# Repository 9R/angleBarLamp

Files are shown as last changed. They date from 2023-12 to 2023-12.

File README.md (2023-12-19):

# Folding AngleBarLamp

This is a folding lamp made out of 3d-printed parts and angle-bars. The design
was inspired by the lamps from 
[kliments workshoptoolset](https://github.com/kliment/workshoptoolset)

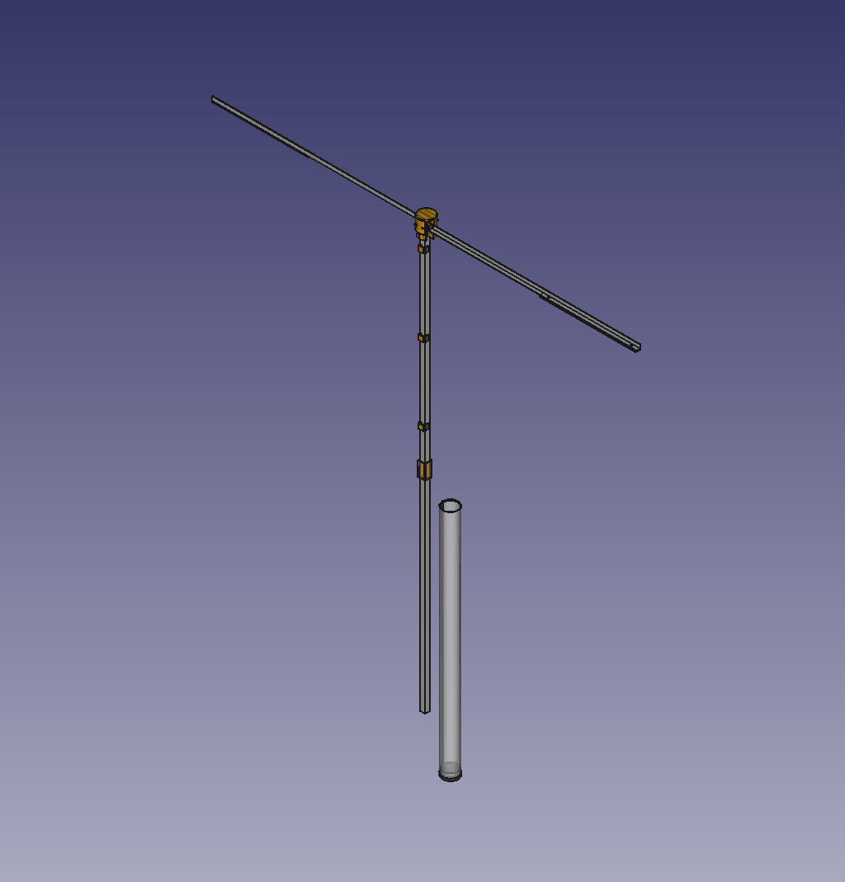
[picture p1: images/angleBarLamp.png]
angle bar lamp


The lamp parts were designed using [Freecad 0.21.1](https://www.freecad.org/)
and the
[assembly4 workbench v0.50.6](https://github.com/Zolko-123/FreeCAD_Assembly4).

## Printed parts

The parts don't require any special settings, recommended print parameters are:

* Tested with PLA, PETG should work as well.
* 4 or 5 perimenter layers
* no support required

### TopBlock

Make sure to print this part upside down to avoid the need for support material
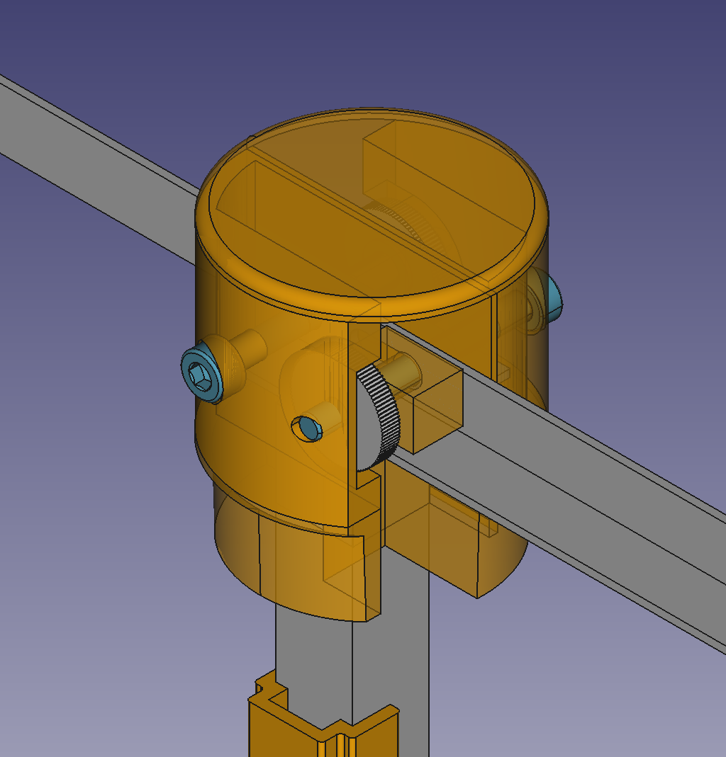
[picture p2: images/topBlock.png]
top block TopBlock


### 8mmSpacer
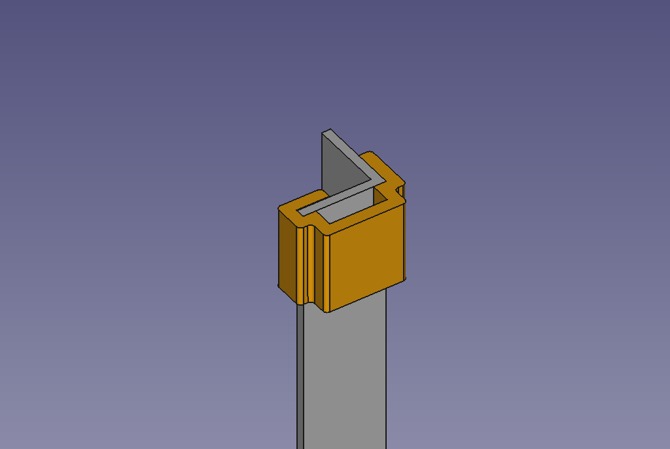
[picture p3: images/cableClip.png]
8mm spacer CableClip


### BottomBlock
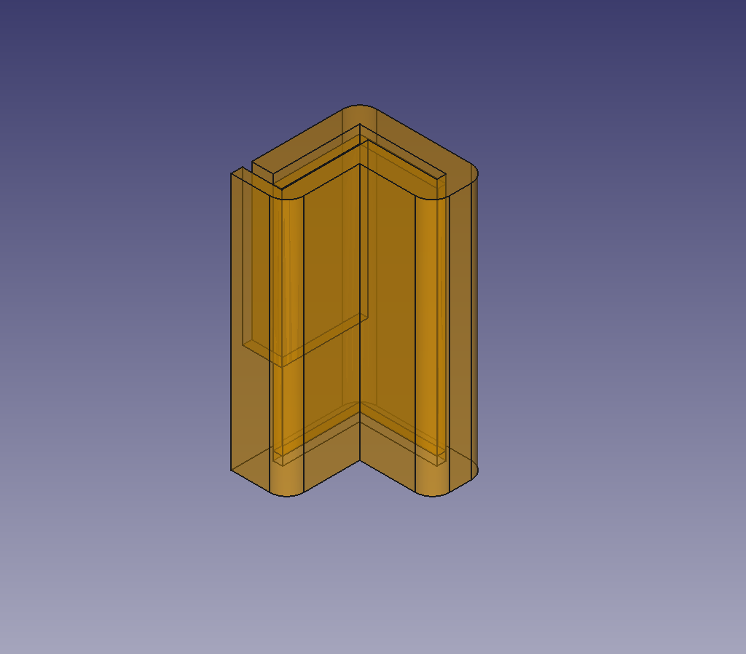
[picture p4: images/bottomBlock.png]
bottom block BottomBlock


### CableClips
cable clip CableClip

### BaseCap

If availabe this part can also be printed in TPU. That way you get a elastic,
more durable bumper at the bottom.
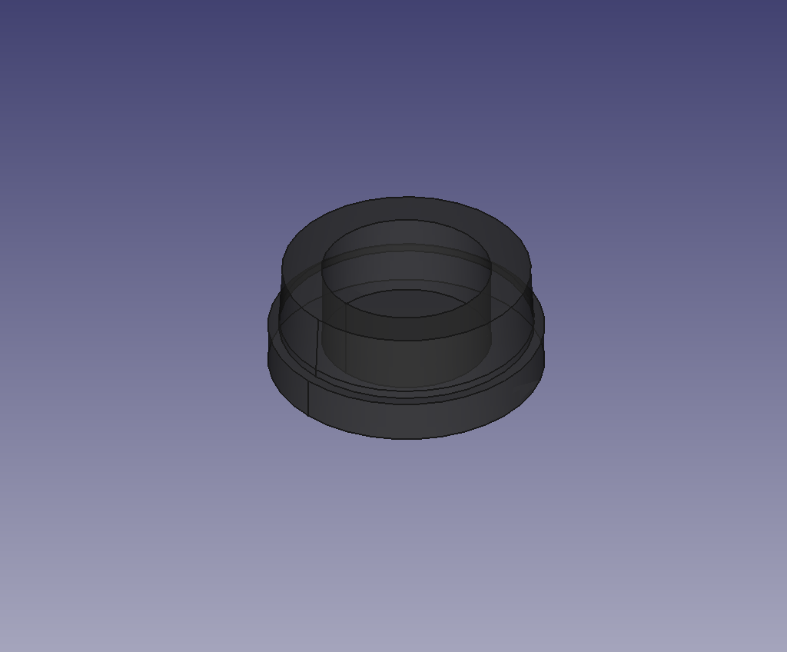
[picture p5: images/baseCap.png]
base cap BaseCap


## Other parts

### Screws & Nuts:
##### topBlock
  * 2x ISO4762 M3x28 hexagonal socket head
  * 2x DIN467 knurled flat nut (or similar)
      
##### COB LED attachment
  * 4x ISO7380-1 M3x4 button head

### Angle bars for arms and foot (length can be modified to suit needs):
  * 2x  8mm x 400mm aluminium angle bar
  * 2x 10mm x 400mm aluminium angle bar

#### 8mm bar latching mechanism
The tips of the 8mm bar need to be machined the create the latching mechanism.
When building a single lamp or a small series this can be done quite easily
by hand using a power drill, a round and a flat files.

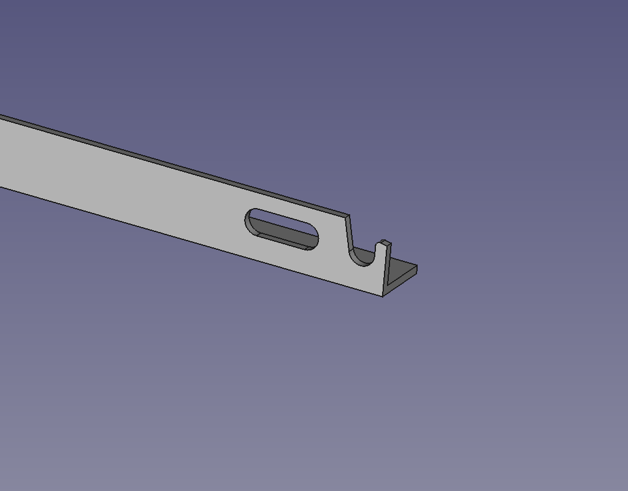
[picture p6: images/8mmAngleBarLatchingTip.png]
8mm angle bar tip 8mm angle bar latching tip


The exact dimensions cna be found in the ```sk_cuts``` sketch in
```angleBarLamp.FCStd```. When machining by hand, it is only important to
position the holes on the center line of the angle bar. Most other dimensions
will allow a tolerance of 0.2mm to still get a working mechanism.

![latch dimensions](images/8mmAngleBarLatchDimensions.png "latch dimensions")

##### Latch jig
A printable jig (```8mmLatchJig.stl```) can be used to transfer these
dimensions in a reproducable way for manual machining.

![latch jig](images/8mmAngleBarLatchJig.png "latch jig")

When building more lamps automating the machining process by generating g-code
for a CNC-mill with FreeCADs 
[Path workbench](https://wiki.freecad.org/Path_Workbench) should be considered.

### Housing
  * 480mm of DN32 HT pipe 

### Electronics:
  * 2x COB LEDs that suite your needs (a width of 8-10mm is recommended)
  * Power supply
  * Switch or dimmer (check workshoptoolset)
  * 2x 1.5m wire

## Folding Mechanism
![folding animation](images/foldingAnimation.gif "Folding mechanism")
![folding animation_closeup](images/foldingAnimationCloseup.gif "Folding mechanismCloseup")

### Running the animation in FreeCAD

* Open the assembly4 workbench
* Run "Animate Assembly" with these parameters

![animation parameters](images/animationParameters.png "")

### Background

This assembly is a top-down design (using a minimal master sketch).

Parts are attached using the master sketch for the axes of the rotating parts
as well as LCSs of adjacent parts.

Animation is controlled by the **time** variable. Nested conditional statements
execute the different parts of the motion as the **time** variable is
incremented. This way rotation and position parameters of the arms are
calculated in the attachment section of moving parts. To keep the expression
managable some intermediate variables are calculated in **Assembly/Variables**.

Some base dimensional parameters are kept in the **Spreadsheet** and can be
modified via the spreadsheet workbench.

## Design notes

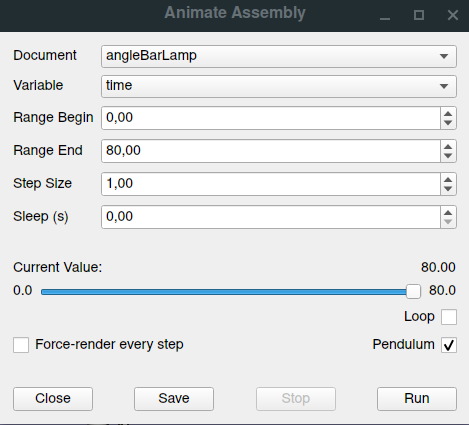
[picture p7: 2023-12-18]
images/animationParameters.png

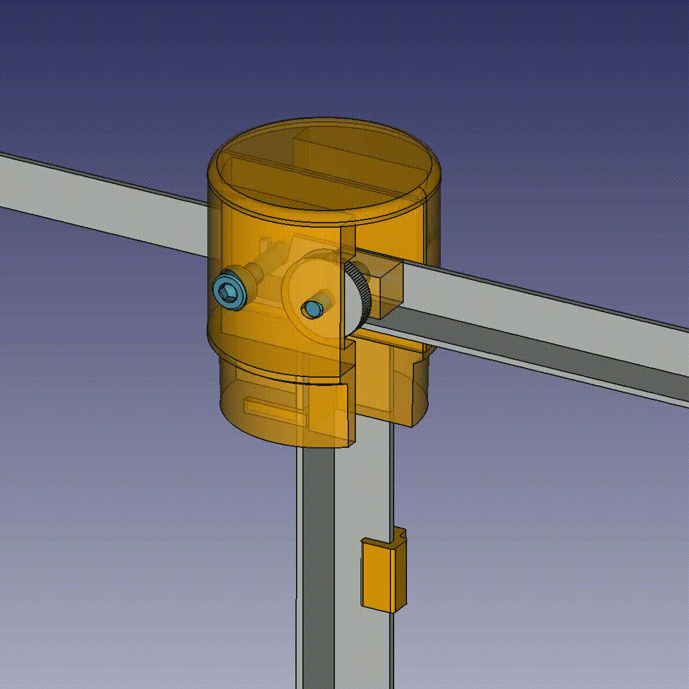
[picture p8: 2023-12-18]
images/foldingAnimationCloseup.gif

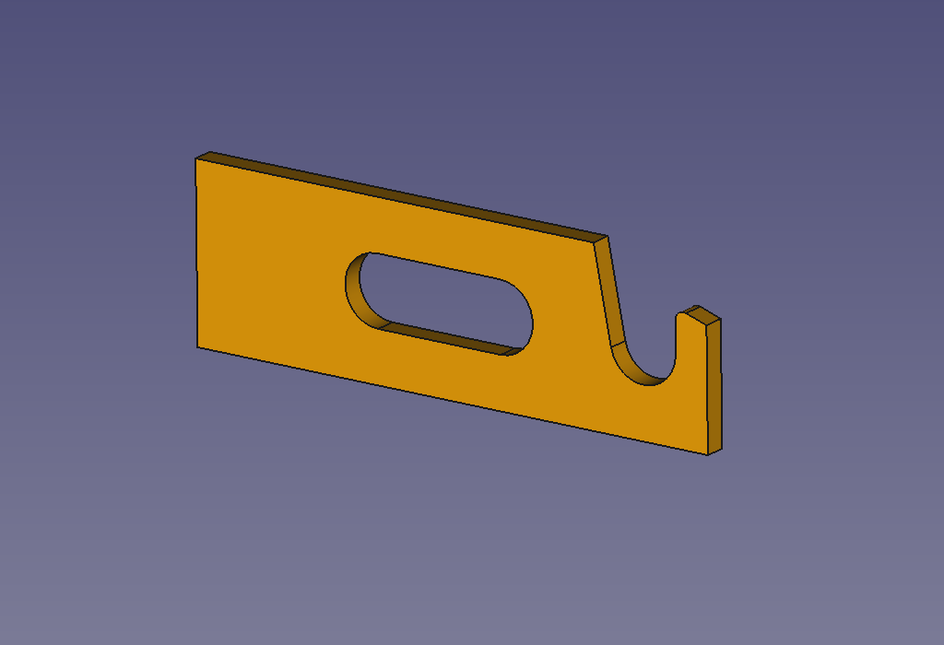
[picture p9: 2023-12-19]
images/8mmAngleBarLatchJig.png

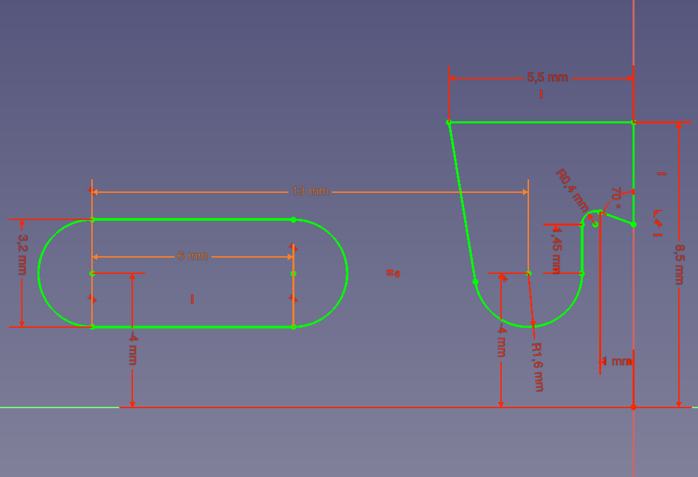
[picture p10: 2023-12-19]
images/8mmAngleBarLatchDimensions.png

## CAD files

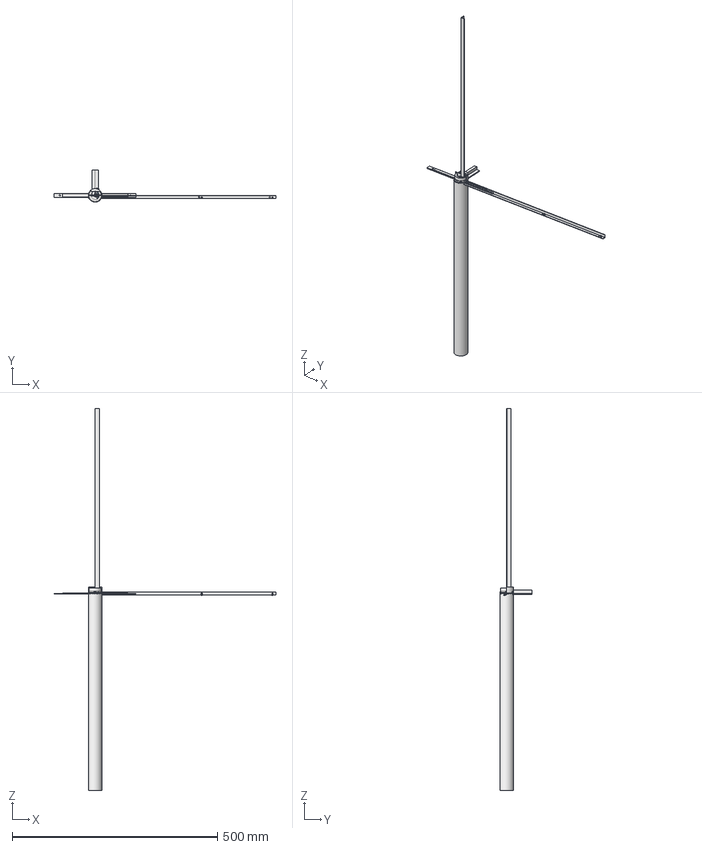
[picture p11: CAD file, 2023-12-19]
angleBarLamp.FCStd
540.0 x 78.5 x 930.0 mm
b_cableClip
template_L-profile_10mm_foot
b_base_cap
M3x28-Screw
M3x4-Screw
M3x4-Screw001
b_LProfile_8mm
b_bottom_connector
b_led
b_led_heatsink
b_nut
b_spacer
b_stencil
b_topBlockArmLock
b_topBlockBase
b_topBlockCap
b_pipe_dn32

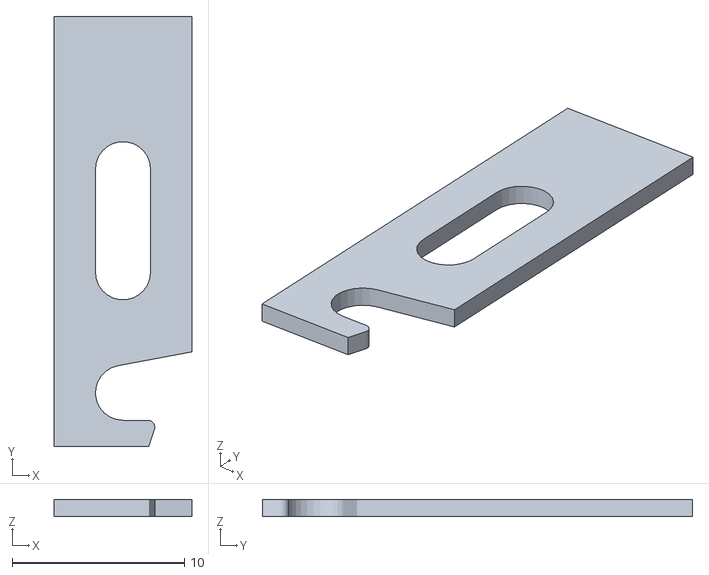
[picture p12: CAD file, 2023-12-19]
STLs/8mmLatchJig.stl
8.00 x 25.0 x 1.00

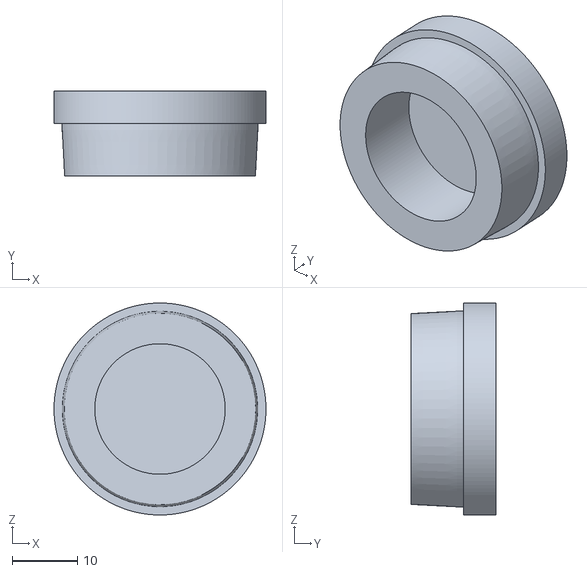
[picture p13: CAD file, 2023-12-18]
STLs/base_cap.stl
32.5 x 13.0 x 32.5

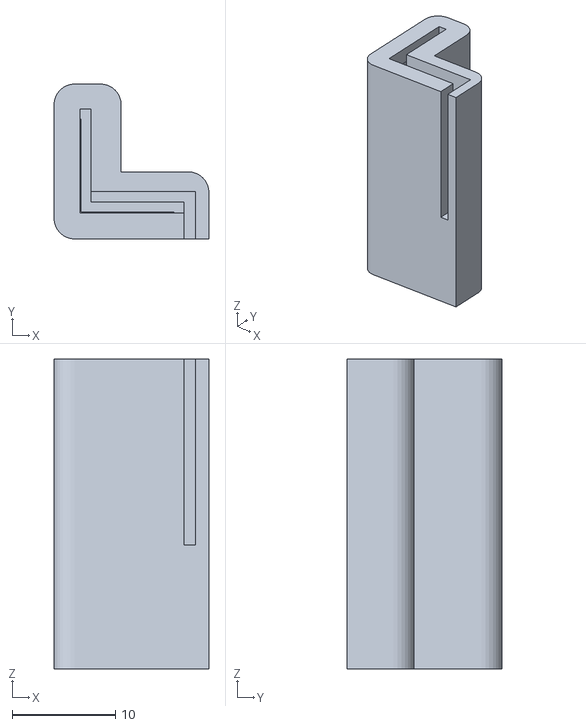
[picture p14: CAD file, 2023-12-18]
STLs/bottomBlock.stl
15.0 x 15.0 x 30.0

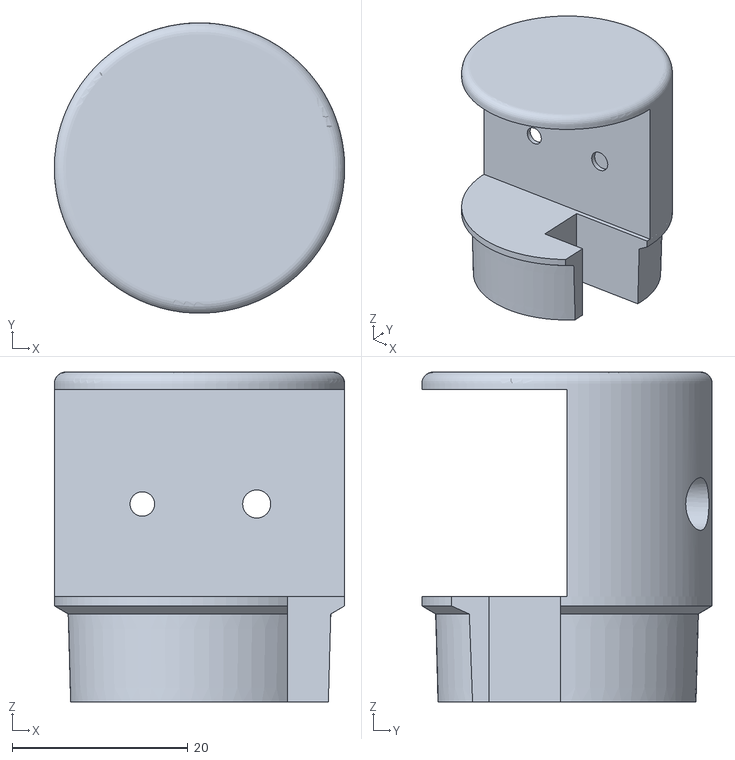
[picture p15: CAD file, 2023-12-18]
STLs/topBlock.stl
33.0 x 33.0 x 37.5

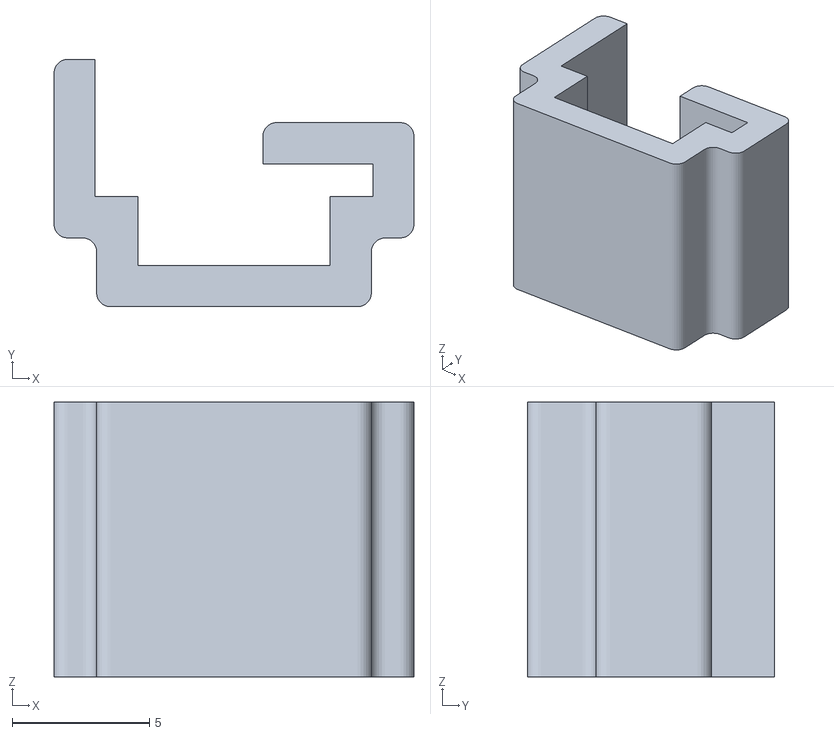
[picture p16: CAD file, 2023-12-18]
STLs/cableClip.stl
13.1 x 9.00 x 10.0

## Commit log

2020-02-20 move assembly into single FCStd and add folding animation
    [Assembly.FCStd, angleBarLamp.FCStd, anglebar10mm.FCStd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]
2020-02-20 add cableClips
    [angleBarLamp.FCStd]
2020-02-20 add .stl files of printed parts
    [bottomBlock.stl, cableClip.stl, topBlock.stl]
2020-02-20 remove obsolete files
    [cableClip.FCStd]
2020-02-20 add cob-led pcbs
    [angleBarLamp.FCStd]
2020-02-20 rebuild bottomBlock without boolean-ops
    [angleBarLamp.FCStd]
2023-12-18 complete redsign
    [angleBarLamp.FCStd, bottomBlock.stl, cableClip.stl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]
2023-12-18 add: base_cap
    [angleBarLamp.FCStd, base_cap.stl]
2023-12-19 Change unit system to Metric small part
    [angleBarLamp.FCStd]
2023-12-19 add: latch jig
    [8mmLatchJig.stl, angleBarLamp.FCStd]
